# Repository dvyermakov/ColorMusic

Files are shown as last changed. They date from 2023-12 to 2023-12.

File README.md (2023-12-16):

### Название

Цветомузыка

### Цели

- Воплотить давнюю задумку.
- Получить опыт разработки аналоговых устройств (усилитель и расчет фильтров).

### Описание

Устройство служит для светового сопровождения музыкальных произведений. 
Состоит из четырех ламп (синего, зеленого, желтого и красного цветов) и блока управления.
Блок питания можно взять любой с напряжением 12 В и силой тока удовлетворяющей нагрузке.

Диапазон звуковой частоты разделен на четыре интервала:
- до 300 Гц для красной лампы
- 300 - 3000 Гц для желтой лампы
- 3000 - 6000 Гц для зеленой лампы
- от 6000 Гц для синей лампы

Лампы выполнены в виде соединенных последовательно-параллельно светодиодов.

В блоке управления все узлы выполнены на отдельных платах для возможности модификации и внесения изменений.

##### Список узлов (плат):
- регуляторы (переменные резисторы)
- усилитель (на ОУ LM358)
- фильтры (полосовые Баттерворта 1 порядка на ОУ LM358)
- ключи (выполнены на полевых транзисторах)
- плата разводки питания

### Использованное ПО, библиотеки.

Разработка схемы и плат - KiCad 7.0.1

### Внешний вид

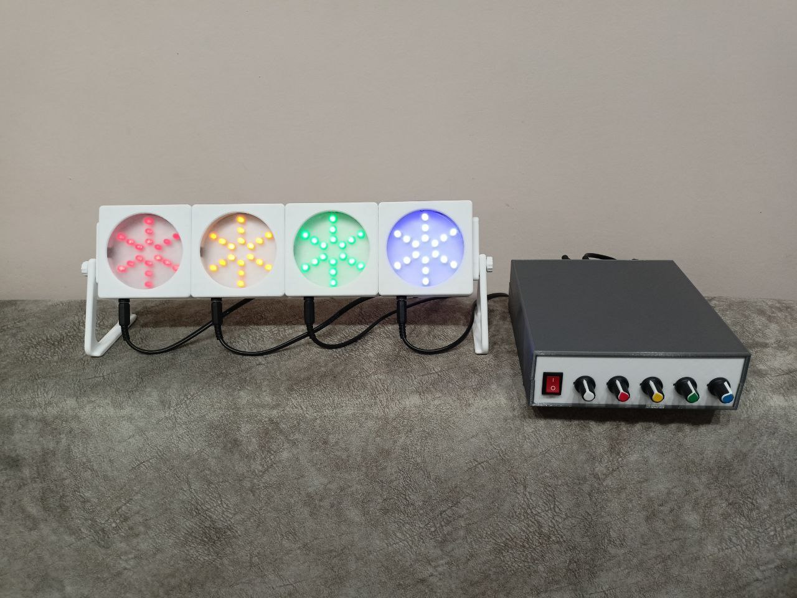
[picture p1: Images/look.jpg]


### Структурная схема



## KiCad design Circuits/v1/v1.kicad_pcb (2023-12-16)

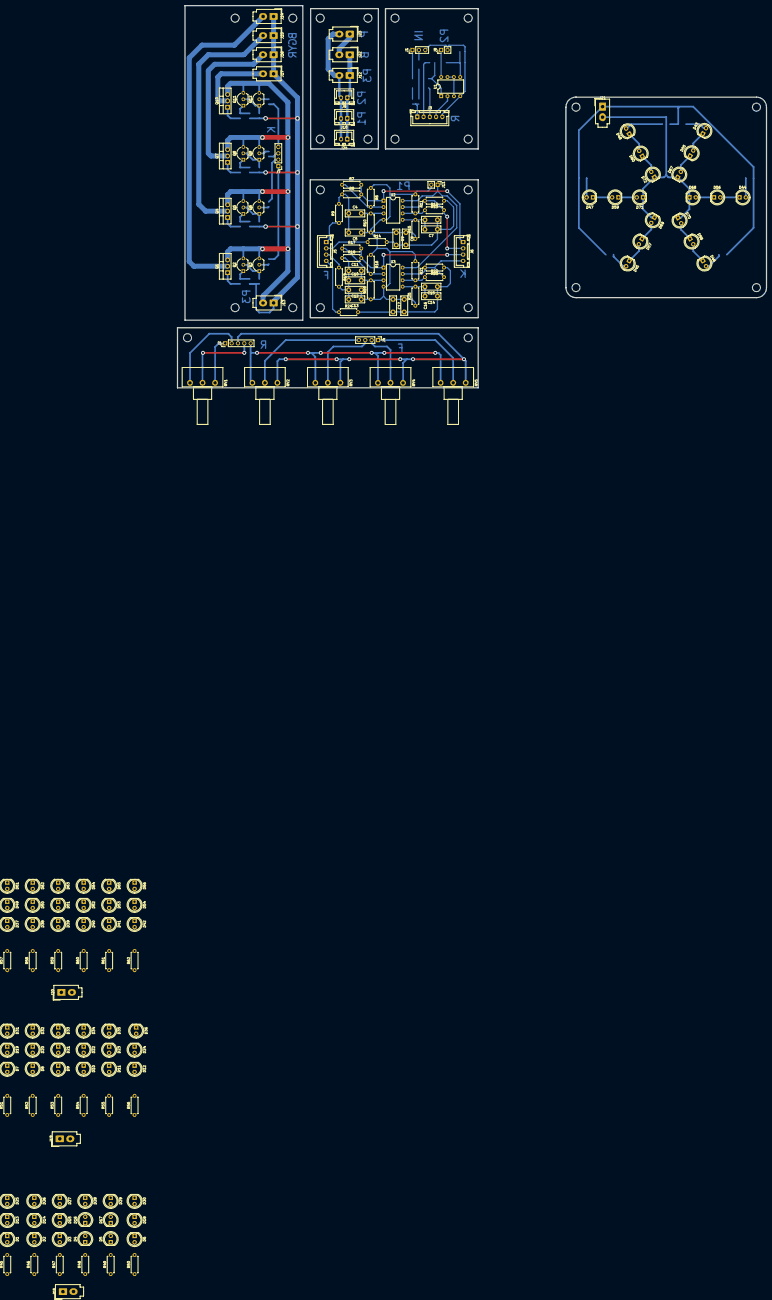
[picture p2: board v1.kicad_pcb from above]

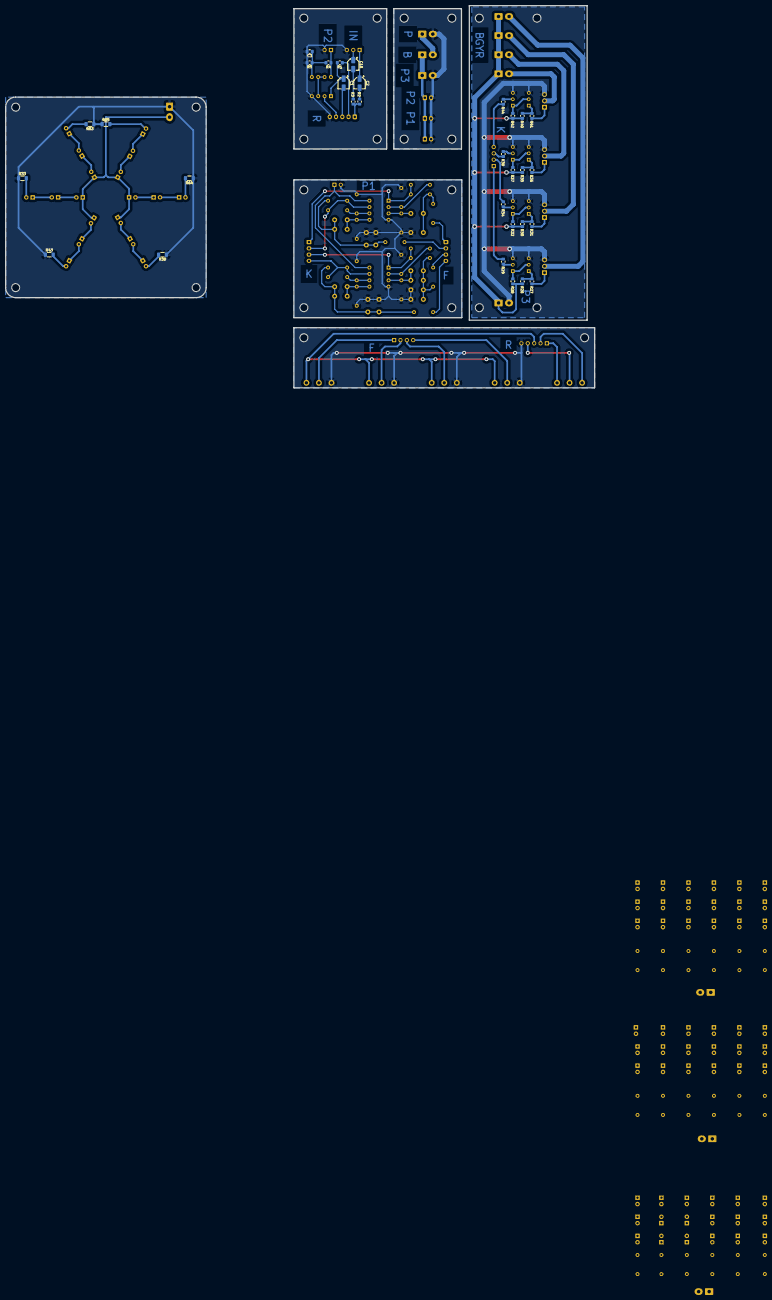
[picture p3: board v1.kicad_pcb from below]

Board: 2 copper layers, 235.0 x 152.5 mm, 221 parts (31 on the bottom side), 153 nets.

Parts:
C1, C2, C18: 1 u; CP_Elec_4x3
C3: 100 n; C_0805_2012Metric_Pad1.18x1.45mm_HandSolder
C4, C5: 3,3 n; C_Disc_D7.5mm_W2.5mm_P5.00mm
C6, C8, C10, C12, C15, C17: 10 n; C_Disc_D7.5mm_W2.5mm_P5.00mm
C7, C9, C11, C13: 1 n; C_Disc_D7.5mm_W2.5mm_P5.00mm
C14, C16: 100 n; C_Disc_D7.5mm_W2.5mm_P5.00mm
D1, D2, D3, D4, D5, D6, D7, D8, D9, D10, D11, D12, D13, D14, D15, D16, D17, D18, D19, D20, D21, D22, D23, D24, D25, D26, D27, D28, D29, D30, D31, D32, D33, D34, D35, D36, D37, D38, D39, D40, D41, D42, D43, D44, D45, D46, D47, D48, D49, D50, D51, D52, D53, D54, D55, D56, D57, D58, D59, D60, D61, D62, D63, D64, D65, D66, D67, D68, D69, D70, D71, D72: LED; LED_D5.0mm
H1, H2, H3, H4, H5, H6, H7, H8, H9, H10, H11, H12, H13, H14, H15, H16, H17, H18, H19, H20, H21, H22: MountingHole; MountingHole_3.2mm_M3
J1: LineIn; PinHeader_1x03_P2.54mm_Vertical
J2: Conn_01x05_Socket; PinHeader_1x05_P2.54mm_Vertical
J3: Conn_01x05_Pin; JST_XH_B5B-XH-A_1x05_P2.50mm_Vertical
J4, J7: Conn_01x04_Socket; PinHeader_1x04_P2.54mm_Vertical
J5, J6: Conn_01x04_Pin; JST_XH_B4B-XH-A_1x04_P2.50mm_Vertical
J8, J11: Conn_01x02_Socket; PinHeader_1x02_P2.54mm_Vertical
J9, J10, J24: Conn_01x02_Pin; JST_XH_B2B-XH-A_1x02_P2.50mm_Vertical
J12, J23: Conn_01x02_Pin; Molex_Mini-Fit_Jr_5566-02A_2x01_P4.20mm_Vertical
J13: Conn_01x02_Socket; Molex_Mini-Fit_Jr_5566-02A_2x01_P4.20mm_Vertical
J14, J18: Blue; Molex_Mini-Fit_Jr_5566-02A_2x01_P4.20mm_Vertical
J15, J19: Green; Molex_Mini-Fit_Jr_5566-02A_2x01_P4.20mm_Vertical
J16, J20: Yellow; Molex_Mini-Fit_Jr_5566-02A_2x01_P4.20mm_Vertical
J17, J21: Red; Molex_Mini-Fit_Jr_5566-02A_2x01_P4.20mm_Vertical
J22: Molex_Mini-Fit_Jr_5566-02A_2x01_P4.20mm_Vertical
Q1, Q4, Q7, Q10: IRF540N; TO-220-3_Vertical
Q2, Q3, Q5, Q6, Q8, Q9, Q11, Q12: BC547; TO-92_Inline_Wide
R1: 100 k; R_0805_2012Metric_Pad1.20x1.40mm_HandSolder
R2, R3, R26, R28, R30, R32, R35, R37, R40, R42: 10 k; R_0805_2012Metric_Pad1.20x1.40mm_HandSolder
R4: 330 k; R_0805_2012Metric_Pad1.20x1.40mm_HandSolder
R5: 150 k; R_0805_2012Metric_Pad1.20x1.40mm_HandSolder
R6, R7, R9, R11, R12, R14, R16, R17, R19, R21, R22, R24: 10 k; R_Axial_DIN0207_L6.3mm_D2.5mm_P7.62mm_Horizontal
R8: 4,7 k; R_Axial_DIN0207_L6.3mm_D2.5mm_P7.62mm_Horizontal
R10: 5,6 k; R_Axial_DIN0207_L6.3mm_D2.5mm_P7.62mm_Horizontal
R13: 2,7 k; R_Axial_DIN0207_L6.3mm_D2.5mm_P7.62mm_Horizontal
R15: 4,3 k; R_Axial_DIN0207_L6.3mm_D2.5mm_P7.62mm_Horizontal
R18: 15 k; R_Axial_DIN0207_L6.3mm_D2.5mm_P7.62mm_Horizontal
R20: 12 k; R_Axial_DIN0207_L6.3mm_D2.5mm_P7.62mm_Horizontal
R23: 24 k; R_Axial_DIN0207_L6.3mm_D2.5mm_P7.62mm_Horizontal
R25: 13 k; R_Axial_DIN0207_L6.3mm_D2.5mm_P7.62mm_Horizontal
R27, R31, R36, R41: 100; R_0805_2012Metric_Pad1.20x1.40mm_HandSolder
R29, R34, R39, R44: 1 k; R_0805_2012Metric_Pad1.20x1.40mm_HandSolder
R33, R38, R43, R63, R64, R65: 390; R_1206_3216Metric_Pad1.30x1.75mm_HandSolder
R45, R46, R47, R48, R49, R50, R51, R52, R53, R54, R55, R56: 180; R_Axial_DIN0207_L6.3mm_D2.5mm_P7.62mm_Horizontal
R57, R58, R59, R60, R61, R62: 390; R_Axial_DIN0207_L6.3mm_D2.5mm_P7.62mm_Horizontal
RV1, RV2, RV3, RV4, RV5: 10 k; Potentiometer_Piher_T-16H_Single_Horizontal
U1, U2, U3: LM358; DIP-8_W7.62mm

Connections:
/Блок питания/+12V: J9.1, J10.1, J12.1, J22.1, J24.1
/Блок питания/GND: J9.2, J10.2, J12.2, J23.2, J24.2
/Ключи/Keys12V: J13.1, J14.1, J15.1, J16.1, J17.1, R26.1, R28.1, R30.1, R32.1, R35.1, R37.1, R40.1, R42.1
/Ключи/KeysBChannel: J7.1, R29.2
/Ключи/KeysGChannel: J7.2, R34.2
/Ключи/KeysGND: J13.2, Q1.3 (S), Q2.3 (E), Q3.3 (E), Q4.3 (S), Q5.3 (E), Q6.3 (E), Q7.3 (S), Q8.3 (E), Q9.3 (E), Q10.3 (S), Q11.3 (E), Q12.3 (E)
/Ключи/KeysRChannel: J7.4, R44.2
/Ключи/KeysYChannel: J7.3, R39.2
/Ключи/LampBlue: J14.2, Q1.2 (D)
/Ключи/LampGreen: J15.2, Q4.2 (D)
/Ключи/LampRed: J17.2, Q10.2 (D)
/Ключи/LampYellow: J16.2, Q7.2 (D)
/Лампы/LampBlue12V: J18.1, R45.1, R46.1, R47.1, R48.1, R49.1, R50.1
/Лампы/LampBlueIn: D25.1 (K), D26.1 (K), D27.1 (K), D28.1 (K), D29.1 (K), D30.1 (K), J18.2
/Лампы/LampGreen12V: J19.1, R51.1, R52.1, R53.1, R54.1, R55.1, R56.1
/Лампы/LampGreenIn: D31.1 (K), D32.1 (K), D33.1 (K), D34.1 (K), D35.1 (K), D36.1 (K), J19.2
/Лампы/LampRed12V: J21.1, R33.1, R38.1, R43.1, R63.1, R64.1, R65.1
/Лампы/LampRedIn: D67.1 (K), D68.1 (K), D69.1 (K), D70.1 (K), D71.1 (K), D72.1 (K), J21.2
/Лампы/LampYellow12V: J20.1, R57.1, R58.1, R59.1, R60.1, R61.1, R62.1
/Лампы/LampYellowIn: D61.1 (K), D62.1 (K), D63.1 (K), D64.1 (K), D65.1 (K), D66.1 (K), J20.2
/Регуляторы/RegAmpOut: J2.3, RV2.3, RV3.3, RV4.3, RV5.3
/Регуляторы/RegBLevel: J4.1, RV5.2
/Регуляторы/RegComLevel1: J2.2, RV1.1
/Регуляторы/RegComLevel2: J2.4, RV1.2
/Регуляторы/RegComLevel3: J2.1, RV1.3
/Регуляторы/RegGLevel: J4.2, RV4.2
/Регуляторы/RegGND: J2.5, RV2.1, RV3.1, RV4.1, RV5.1
/Регуляторы/RegRLevel: J4.4, RV2.2
/Регуляторы/RegYLevel: J4.3, RV3.2
/Усилитель/Amp12V: J8.1, R4.1, U1.8 (V+)
/Усилитель/AmpComLevel1: J3.2, R1.2
/Усилитель/AmpComLevel2: J3.4, U1.2 (-)
/Усилитель/AmpComLevel3: J3.1, R2.1, R3.1
/Усилитель/AmpGND: C3.2, J1.3, J3.5, J8.2, R5.2, U1.4 (V-)
/Усилитель/AmpOut: C1.2, J3.3
/Усилитель/LineInL: C18.1, J1.2
/Усилитель/LineInR: C2.1, J1.1
/Фильтры/Fil12V: J11.1, U2.8 (V+), U3.8 (V+)
/Фильтры/FilBChannel: J6.1, R7.2, R8.2, U2.1
/Фильтры/FilBLevel: J5.1, R9.1
/Фильтры/FilGChannel: J6.2, R12.2, R13.2, U2.7
/Фильтры/FilGLevel: J5.2, R14.1
/Фильтры/FilGND: C5.1, C8.1, C9.1, C12.1, C13.1, C16.1, C17.1, J11.2, R6.1, R10.1, R11.1, R15.1, R16.1, R20.1, R21.1, R25.1, U2.4 (V-), U3.4 (V-)
/Фильтры/FilRChannel: J6.4, R22.2, R23.2, U3.7
/Фильтры/FilRLevel: J5.4, R24.1
/Фильтры/FilYChannel: J6.3, R17.2, R18.2, U3.1
/Фильтры/FilYLevel: J5.3, R19.1
GNDREF: U1.3 (+), U1.6 (-), U1.7
unnamed: C1.1, R1.1, U1.1
unnamed: C2.2, R2.2
unnamed: C4.1, C5.2, R8.1, R9.2
unnamed: C6.1, C7.1, C8.2, C9.2, R13.1, R14.2
unnamed: C10.1, C11.1, C12.2, C13.2, R18.1, R19.2
unnamed: C14.1, C15.1, C16.2, C17.2, R23.1, R24.2
unnamed: C18.2, R3.2
unnamed: D1.2 (A), R45.2
unnamed: D1.1 (K), D13.2 (A)
unnamed: D2.2 (A), R46.2
unnamed: D3.2 (A), R47.2
unnamed: D4.2 (A), R48.2
unnamed: D5.2 (A), R49.2
unnamed: D6.2 (A), R50.2
unnamed: D7.2 (A), R51.2
unnamed: D8.2 (A), R52.2
unnamed: D9.2 (A), R53.2
unnamed: D10.2 (A), R54.2
unnamed: D10.1 (K), D22.2 (A)
unnamed: D11.2 (A), R55.2
unnamed: D11.1 (K), D23.2 (A)
unnamed: D12.2 (A), R56.2
unnamed: D12.1 (K), D24.2 (A)
unnamed: D13.1 (K), D25.2 (A)
unnamed: D2.1 (K), D14.2 (A)
unnamed: D14.1 (K), D26.2 (A)
unnamed: D3.1 (K), D15.2 (A)
unnamed: D15.1 (K), D27.2 (A)
unnamed: D4.1 (K), D16.2 (A)
unnamed: D16.1 (K), D28.2 (A)
unnamed: D5.1 (K), D17.2 (A)
unnamed: D17.1 (K), D29.2 (A)
unnamed: D6.1 (K), D18.2 (A)
unnamed: D18.1 (K), D30.2 (A)
unnamed: D7.1 (K), D19.2 (A)
unnamed: D19.1 (K), D31.2 (A)
unnamed: D8.1 (K), D20.2 (A)
unnamed: D20.1 (K), D32.2 (A)
unnamed: D9.1 (K), D21.2 (A)
unnamed: D21.1 (K), D33.2 (A)
unnamed: D22.1 (K), D34.2 (A)
unnamed: D23.1 (K), D35.2 (A)
unnamed: D24.1 (K), D36.2 (A)
unnamed: D37.2 (A), R57.2
unnamed: D37.1 (K), D49.2 (A)
unnamed: D38.2 (A), R58.2
unnamed: D38.1 (K), D50.2 (A)
unnamed: D39.2 (A), R59.2
unnamed: D39.1 (K), D51.2 (A)
unnamed: D40.2 (A), R60.2
unnamed: D40.1 (K), D52.2 (A)
unnamed: D41.2 (A), R61.2
unnamed: D41.1 (K), D53.2 (A)
unnamed: D42.2 (A), R62.2
unnamed: D42.1 (K), D54.2 (A)
unnamed: D43.2 (A), R63.2
unnamed: D43.1 (K), D55.2 (A)
unnamed: D44.2 (A), R33.2
unnamed: D44.1 (K), D56.2 (A)
unnamed: D45.2 (A), R38.2
unnamed: D45.1 (K), D57.2 (A)
unnamed: D46.2 (A), R43.2
unnamed: D46.1 (K), D58.2 (A)
unnamed: D47.2 (A), R64.2
unnamed: D47.1 (K), D59.2 (A)
unnamed: D48.2 (A), R65.2
unnamed: D48.1 (K), D60.2 (A)
unnamed: D49.1 (K), D61.2 (A)
unnamed: D50.1 (K), D62.2 (A)
unnamed: D51.1 (K), D63.2 (A)
unnamed: D52.1 (K), D64.2 (A)
unnamed: D53.1 (K), D65.2 (A)
unnamed: D54.1 (K), D66.2 (A)
unnamed: D55.1 (K), D67.2 (A)
unnamed: D56.1 (K), D68.2 (A)
unnamed: D57.1 (K), D69.2 (A)
unnamed: D58.1 (K), D70.2 (A)
unnamed: D59.1 (K), D71.2 (A)
unnamed: D60.1 (K), D72.2 (A)
unnamed: J22.2, J23.1
unnamed: Q1.1 (G), R27.1
unnamed: Q2.2 (B), Q3.1 (C), R28.2
unnamed: Q2.1 (C), R26.2, R27.2
unnamed: Q3.2 (B), R29.1
unnamed: Q4.1 (G), R31.1
unnamed: Q5.2 (B), Q6.1 (C), R32.2
unnamed: Q5.1 (C), R30.2, R31.2
unnamed: Q6.2 (B), R34.1
unnamed: Q7.1 (G), R36.1
unnamed: Q8.2 (B), Q9.1 (C), R37.2
unnamed: Q8.1 (C), R35.2, R36.2
unnamed: Q9.2 (B), R39.1
unnamed: Q10.1 (G), R41.1
unnamed: Q11.2 (B), Q12.1 (C), R42.2
unnamed: Q11.1 (C), R40.2, R41.2
unnamed: Q12.2 (B), R44.1
unnamed: C3.1, R4.2, R5.1, U1.5 (+)
unnamed: C4.2, R10.2, U2.3 (+)
unnamed: R6.2, R7.1, U2.2 (-)
unnamed: C6.2, C7.2, R15.2, U2.5 (+)
unnamed: R11.2, R12.1, U2.6 (-)
unnamed: C10.2, C11.2, R20.2, U3.3 (+)
unnamed: R16.2, R17.1, U3.2 (-)
unnamed: C14.2, C15.2, R25.2, U3.5 (+)
unnamed: R21.2, R22.1, U3.6 (-)
